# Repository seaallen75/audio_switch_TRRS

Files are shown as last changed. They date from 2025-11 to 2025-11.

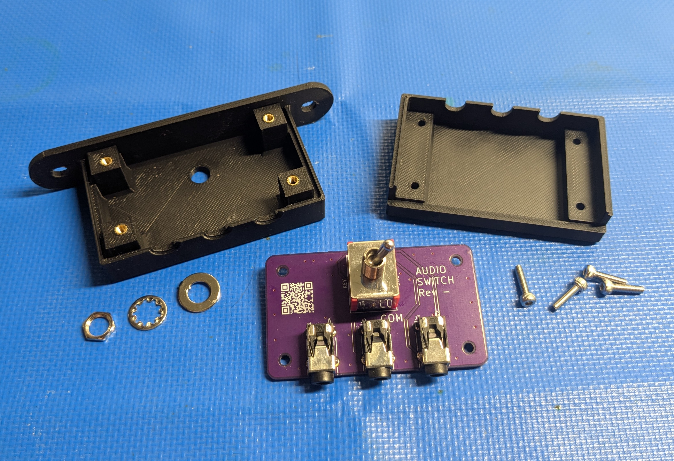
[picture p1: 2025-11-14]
pictures/audio_switch_disassembled.jpg

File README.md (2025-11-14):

# audio_switch_TRRS
A 3.5mm TRRS audio switch, COM to A or B

I got tired of fumbling around under my desk to switch my audio connection between a headset and a speaker bar so I created a simple 3.5mm TRRS audio switch with KiCad and FreeCAD. 

The PCB was designed in KiCad. The gerbers can be found in gerbers/audio_switch_gerbers.zip and can be sent to any PCB fabricator. The PCB should be made 1.6mm thick to fit with the case. The [toggle switch](https://www.digikey.com/en/products/detail/e-switch/1003P1T1B1M2QEH/378894) and [3.5mm audio jacks](https://www.digikey.com/en/products/detail/tensility-international-corp/54-00174/12140150) are soldered to the PCB. 

The case was designed in FreeCAD. The .step models are available as well as a Bambu Studio file (.3mf) for printing on a Bambu 3D printer. M2.5x4x3.5 threaded heat-set inserts are pressed into the front piece of the case. A vertical heat-set insert press tool makes it much easier to install all of the threaded inserts straight up and down. The back piece of the case is secured with M2.5x10 screws. The case is designed to be mounted with Kreg pocket-hole screws. 

audio_switch_mounted

audio_switch_disassembled

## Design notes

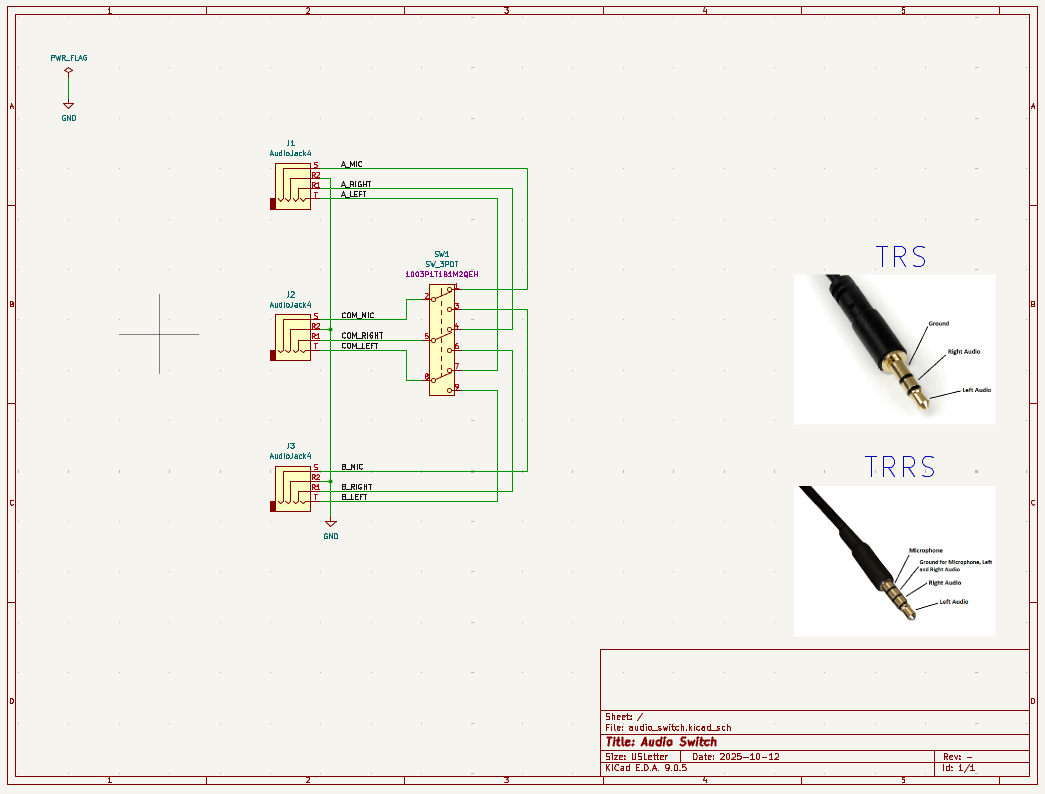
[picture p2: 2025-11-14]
pictures/audio_switch_KiCad_schematic.png

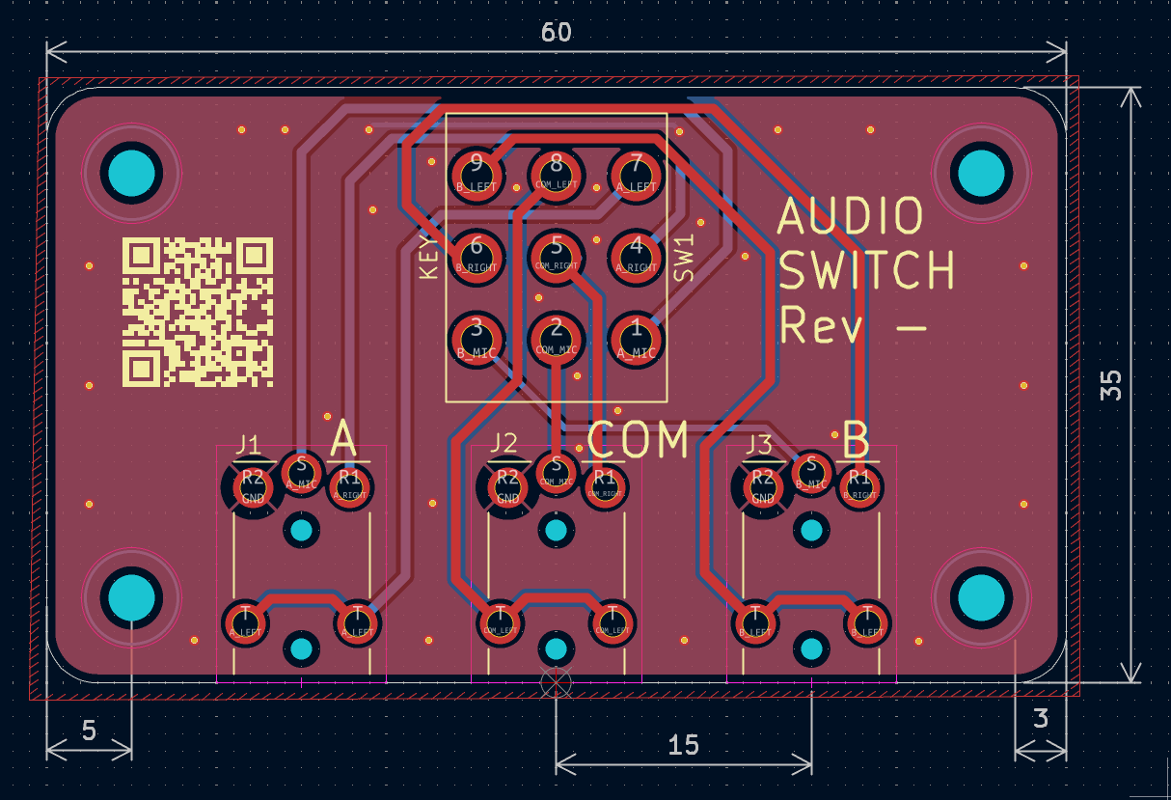
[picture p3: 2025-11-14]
pictures/audio_switch_KiCad_layout.png

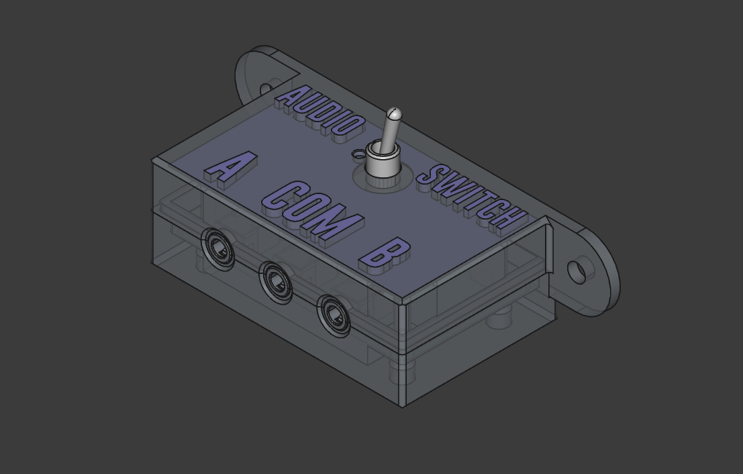
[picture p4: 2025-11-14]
pictures/audio_switch_FreeCAD_transparent.png

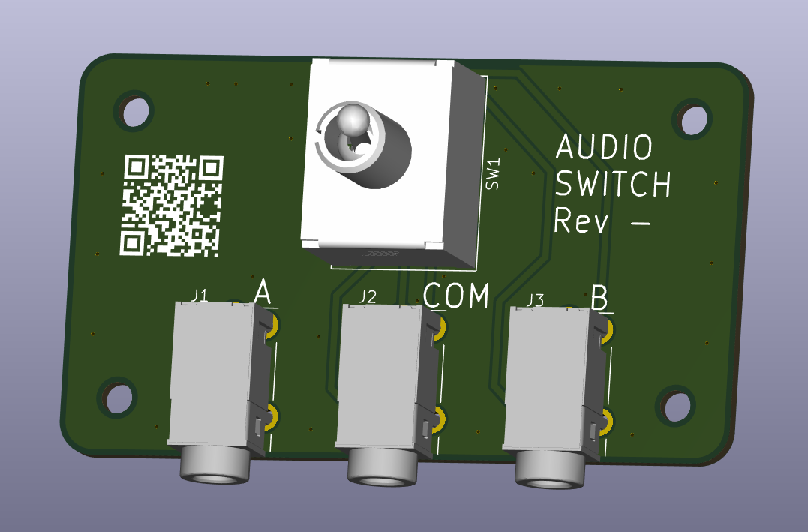
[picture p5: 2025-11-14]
pictures/audio_switch_KiCad_3D.png

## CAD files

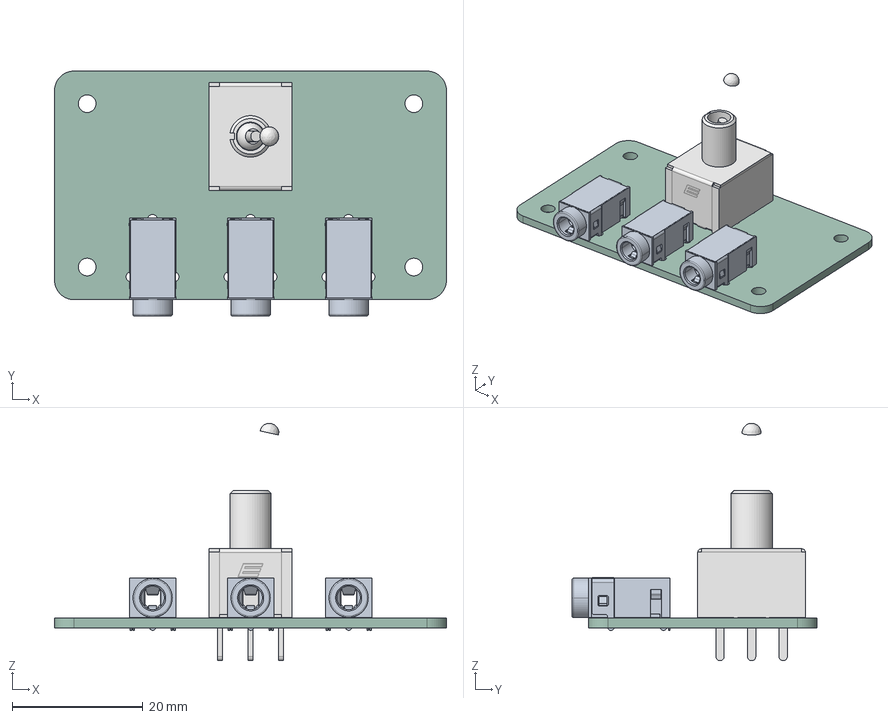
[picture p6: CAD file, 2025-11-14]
audio_switch_CCA.step
60.0 x 37.5 x 36.3 mm
54-00174_housing x 3
54-00174_#1 x 3
54-00174_#3 x 3
54-00174_#2 x 3
54-00174_#4 x 3
1003PxT1B1M2xE
audio_switch_PCB

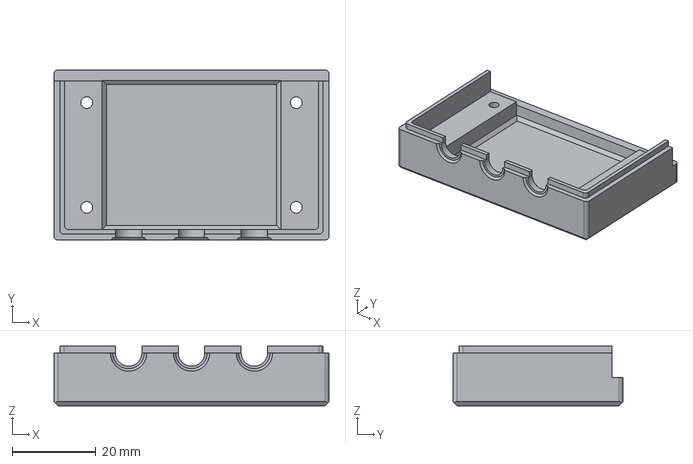
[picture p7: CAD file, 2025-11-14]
case_back.step
65.6 x 40.6 x 14.2 mm

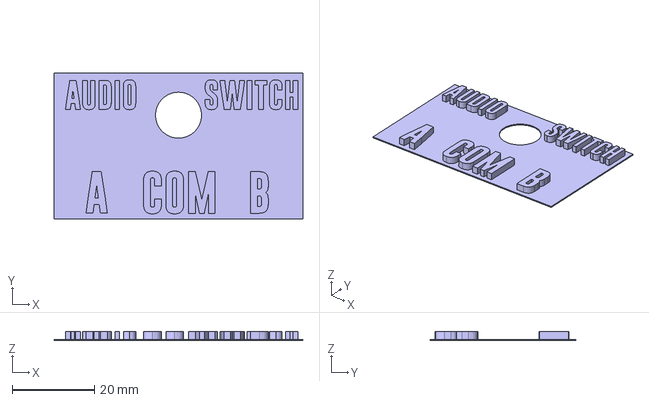
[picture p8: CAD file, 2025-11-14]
case_front_inlay.step
60.6 x 35.6 x 2.20 mm

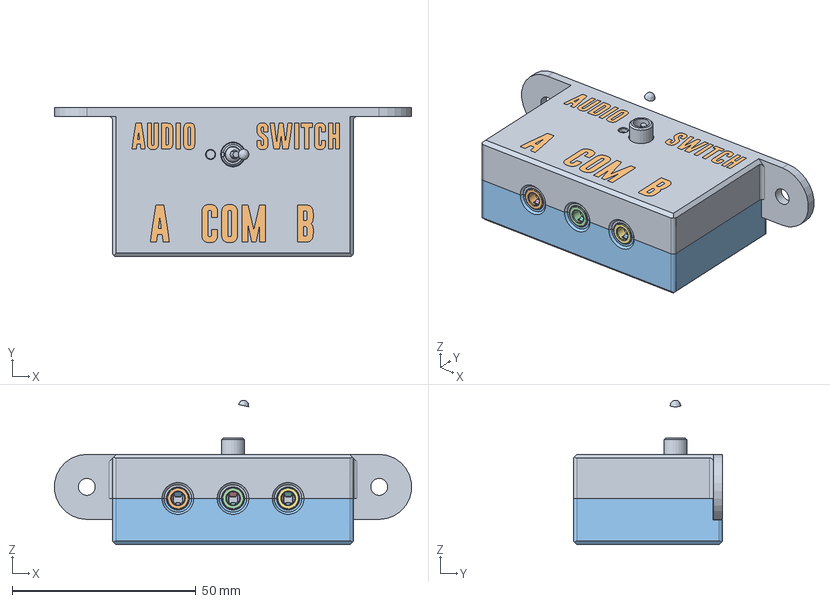
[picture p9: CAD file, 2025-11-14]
audio_switch_case.FCStd
97.2 x 40.6 x 39.3 mm
Body_case_front
Body_case_front_inlay
Body_case_back
54-00174_housing
54-00174_#1
54-00174_#3
54-00174_#2
54-00174_#4
1003PxT1B1M2xE
54-00174_housing001
54-00174_#005
54-00174_#006
54-00174_#007
54-00174_#008
54-00174_housing002
54-00174_#009
54-00174_#010
54-00174_#011
54-00174_#012
audio_switch_PCB

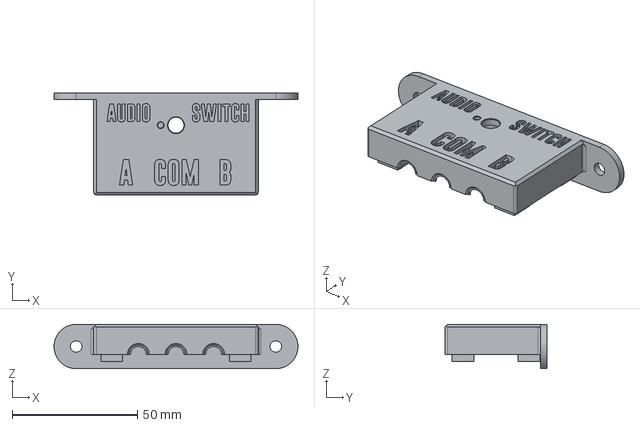
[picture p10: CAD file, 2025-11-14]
case_front.step
97.3 x 40.6 x 17.7 mm

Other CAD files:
audio_switch_case.3mf

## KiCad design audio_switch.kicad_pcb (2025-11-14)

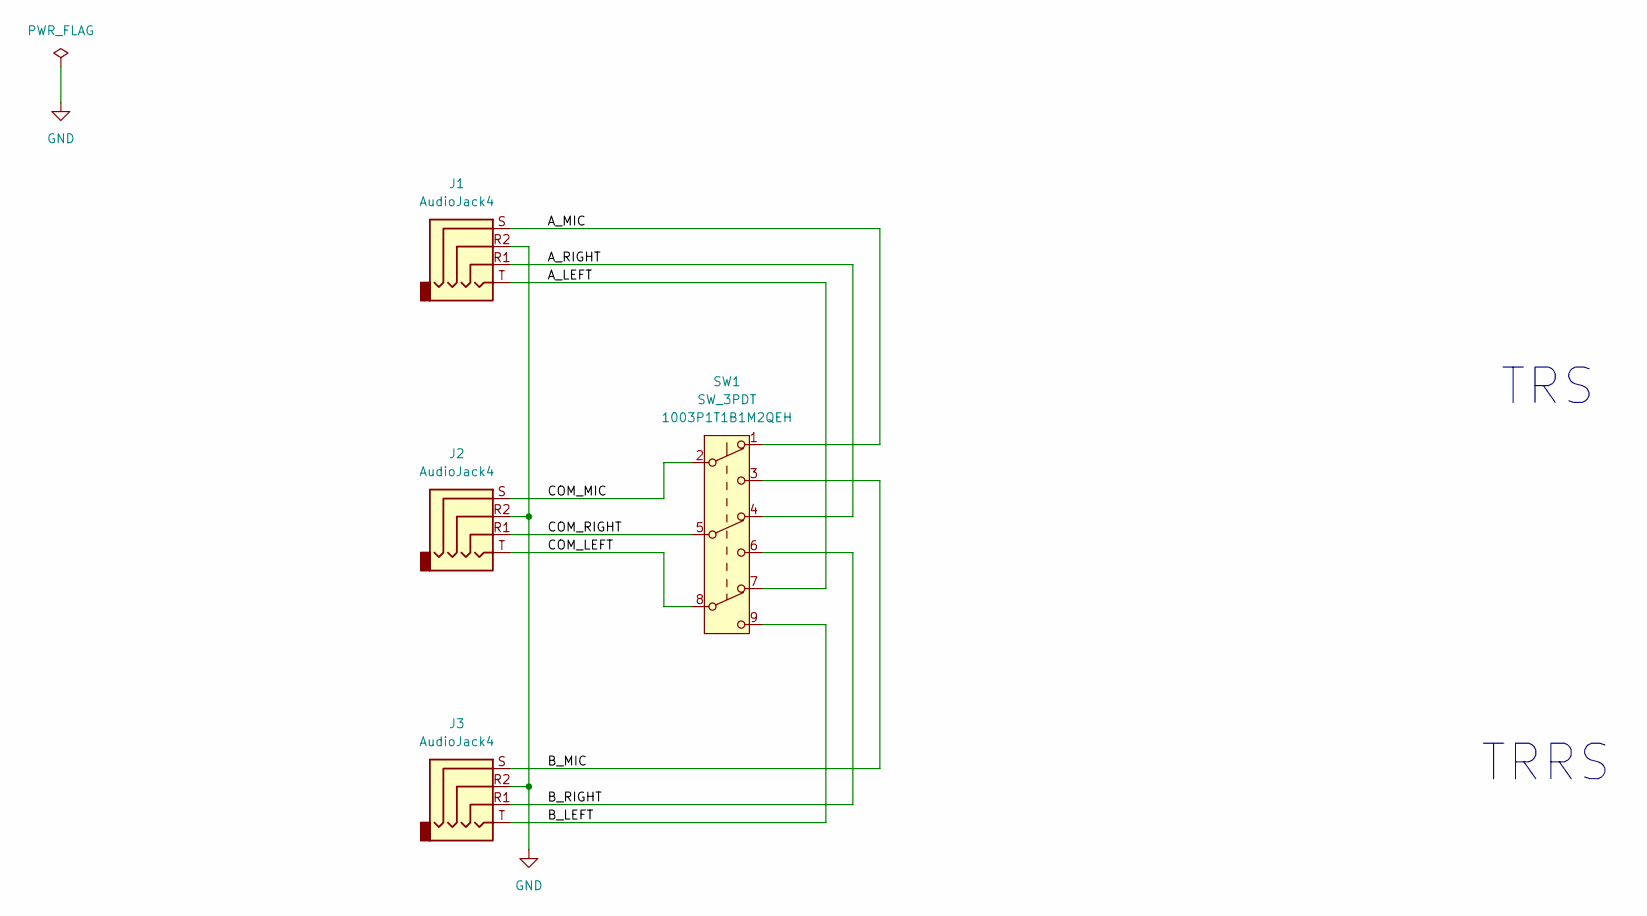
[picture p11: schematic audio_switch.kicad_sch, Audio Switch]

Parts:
J1, J2, J3: AudioJack4; 54-00174; MPN 54-00174
SW1: SW_3PDT; 1003P1T1B1M2QEH; MPN 1003P1T1B1M2QEH

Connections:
/A_LEFT: J1.T, SW1.7 (A)
/A_MIC: J1.S, SW1.1 (A)
/A_RIGHT: J1.R1, SW1.4 (A)
/B_LEFT: J3.T, SW1.9 (C)
/B_MIC: J3.S, SW1.3 (C)
/B_RIGHT: J3.R1, SW1.6 (C)
/COM_LEFT: J2.T, SW1.8 (B)
/COM_MIC: J2.S, SW1.2 (B)
/COM_RIGHT: J2.R1, SW1.5 (B)
GND: J1.R2, J2.R2, J3.R2

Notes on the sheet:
TRS
TRRS

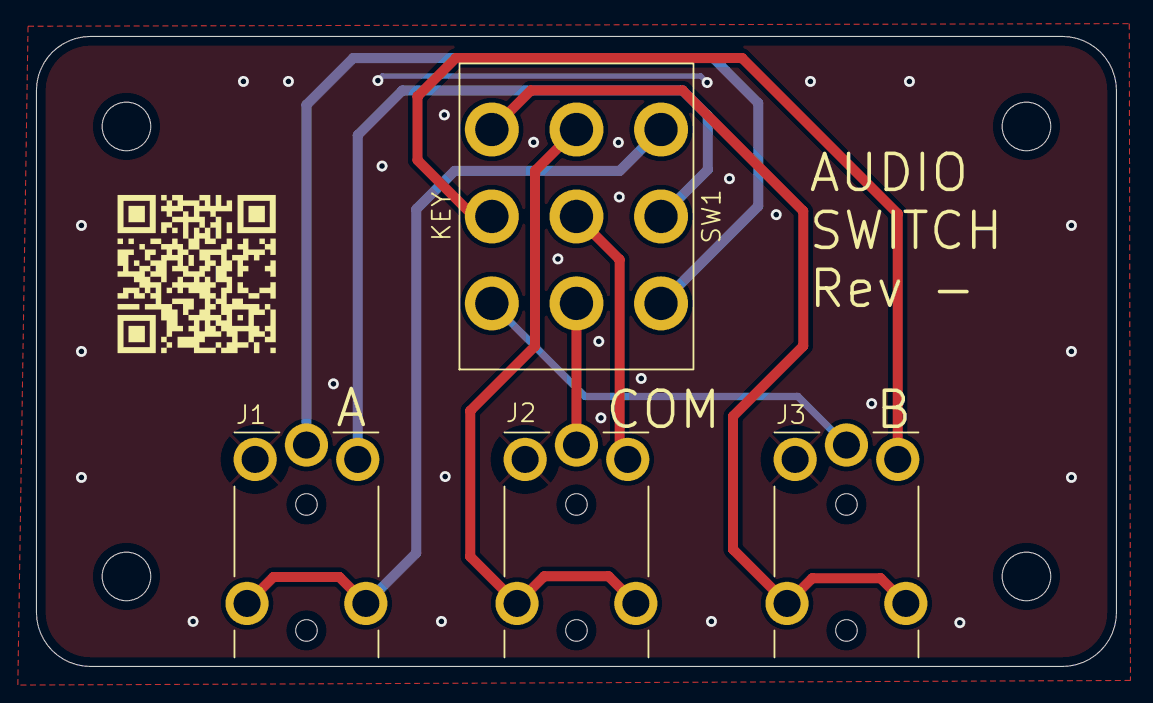
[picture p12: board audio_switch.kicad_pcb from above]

Board: 2 copper layers, 60.0 x 35.0 mm, 4 parts (0 on the bottom side), 10 nets.
